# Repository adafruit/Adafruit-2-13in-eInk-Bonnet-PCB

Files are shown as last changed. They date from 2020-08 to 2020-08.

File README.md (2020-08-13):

## Adafruit 2.13" Monochrome eInk Bonnet for Raspberry Pi PCB

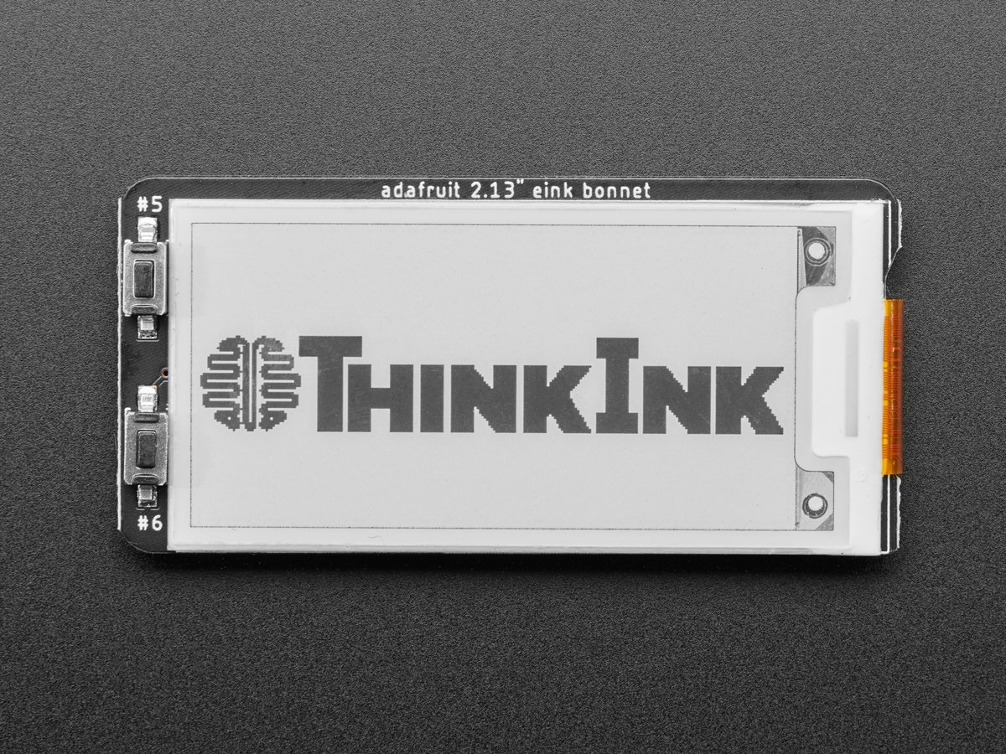
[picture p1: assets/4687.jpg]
<a href="http://www.adafruit.com/products/4687"><br/>
Click here to purchase one from the Adafruit shop</a>

PCB files for the Adafruit 2.13" Monochrome eInk Bonnet for Raspberry Pi.

Format is EagleCAD schematic and board layout
* https://www.adafruit.com/product/4687

### Description

Easy e-paper finally comes to Raspberry Pi, with this bonnet that's designed to make it a breeze to add a 2.13" 250x122 crisp monochromic eInk display. Chances are you've seen one of those new-fangled 'e-readers' like the Kindle or Nook. They have gigantic electronic paper 'static' displays - that means the image stays on the display even when power is completely disconnected. The image is also high contrast and very daylight readable. It really does look just like printed paper!

The Adafruit 2.13" Monochrome E-Ink Bonnet for Raspberry Pi snaps onto any modern Raspberry Pi and provides a Python-programmable display with two buttons that can be used to select programs or scroll through options.

We have two fun starter guides to use with this bonnet, an Open Weather display and an event calendar that auto-syncs with a Google Calendar to show you what your next meeting or event is. We also have examples in our E-Ink Python library you can use to craft your own project

Comes completely pre-assembled and tested so you don't need to do anything but plug it in and install our Python code! Works with any Raspberry Pi computer that has a 2x20 connector, such as the Pi B+, Pi 2, Pi 3, Pi 4, and Pi Zero (and any others that have a 2x20 connector!)

On the bottom, we have a Qwiic/STEMMA QT connector for I2C sensors and devices so you can plug and play any of our STEMMA QT devices.

### License

Adafruit invests time and resources providing this open source design, please support Adafruit and open-source hardware by purchasing products from [Adafruit](https://www.adafruit.com)!

Designed by Limor Fried/Ladyada for Adafruit Industries.

Creative Commons Attribution/Share-Alike, all text above must be included in any redistribution.
See license.txt for additional details.

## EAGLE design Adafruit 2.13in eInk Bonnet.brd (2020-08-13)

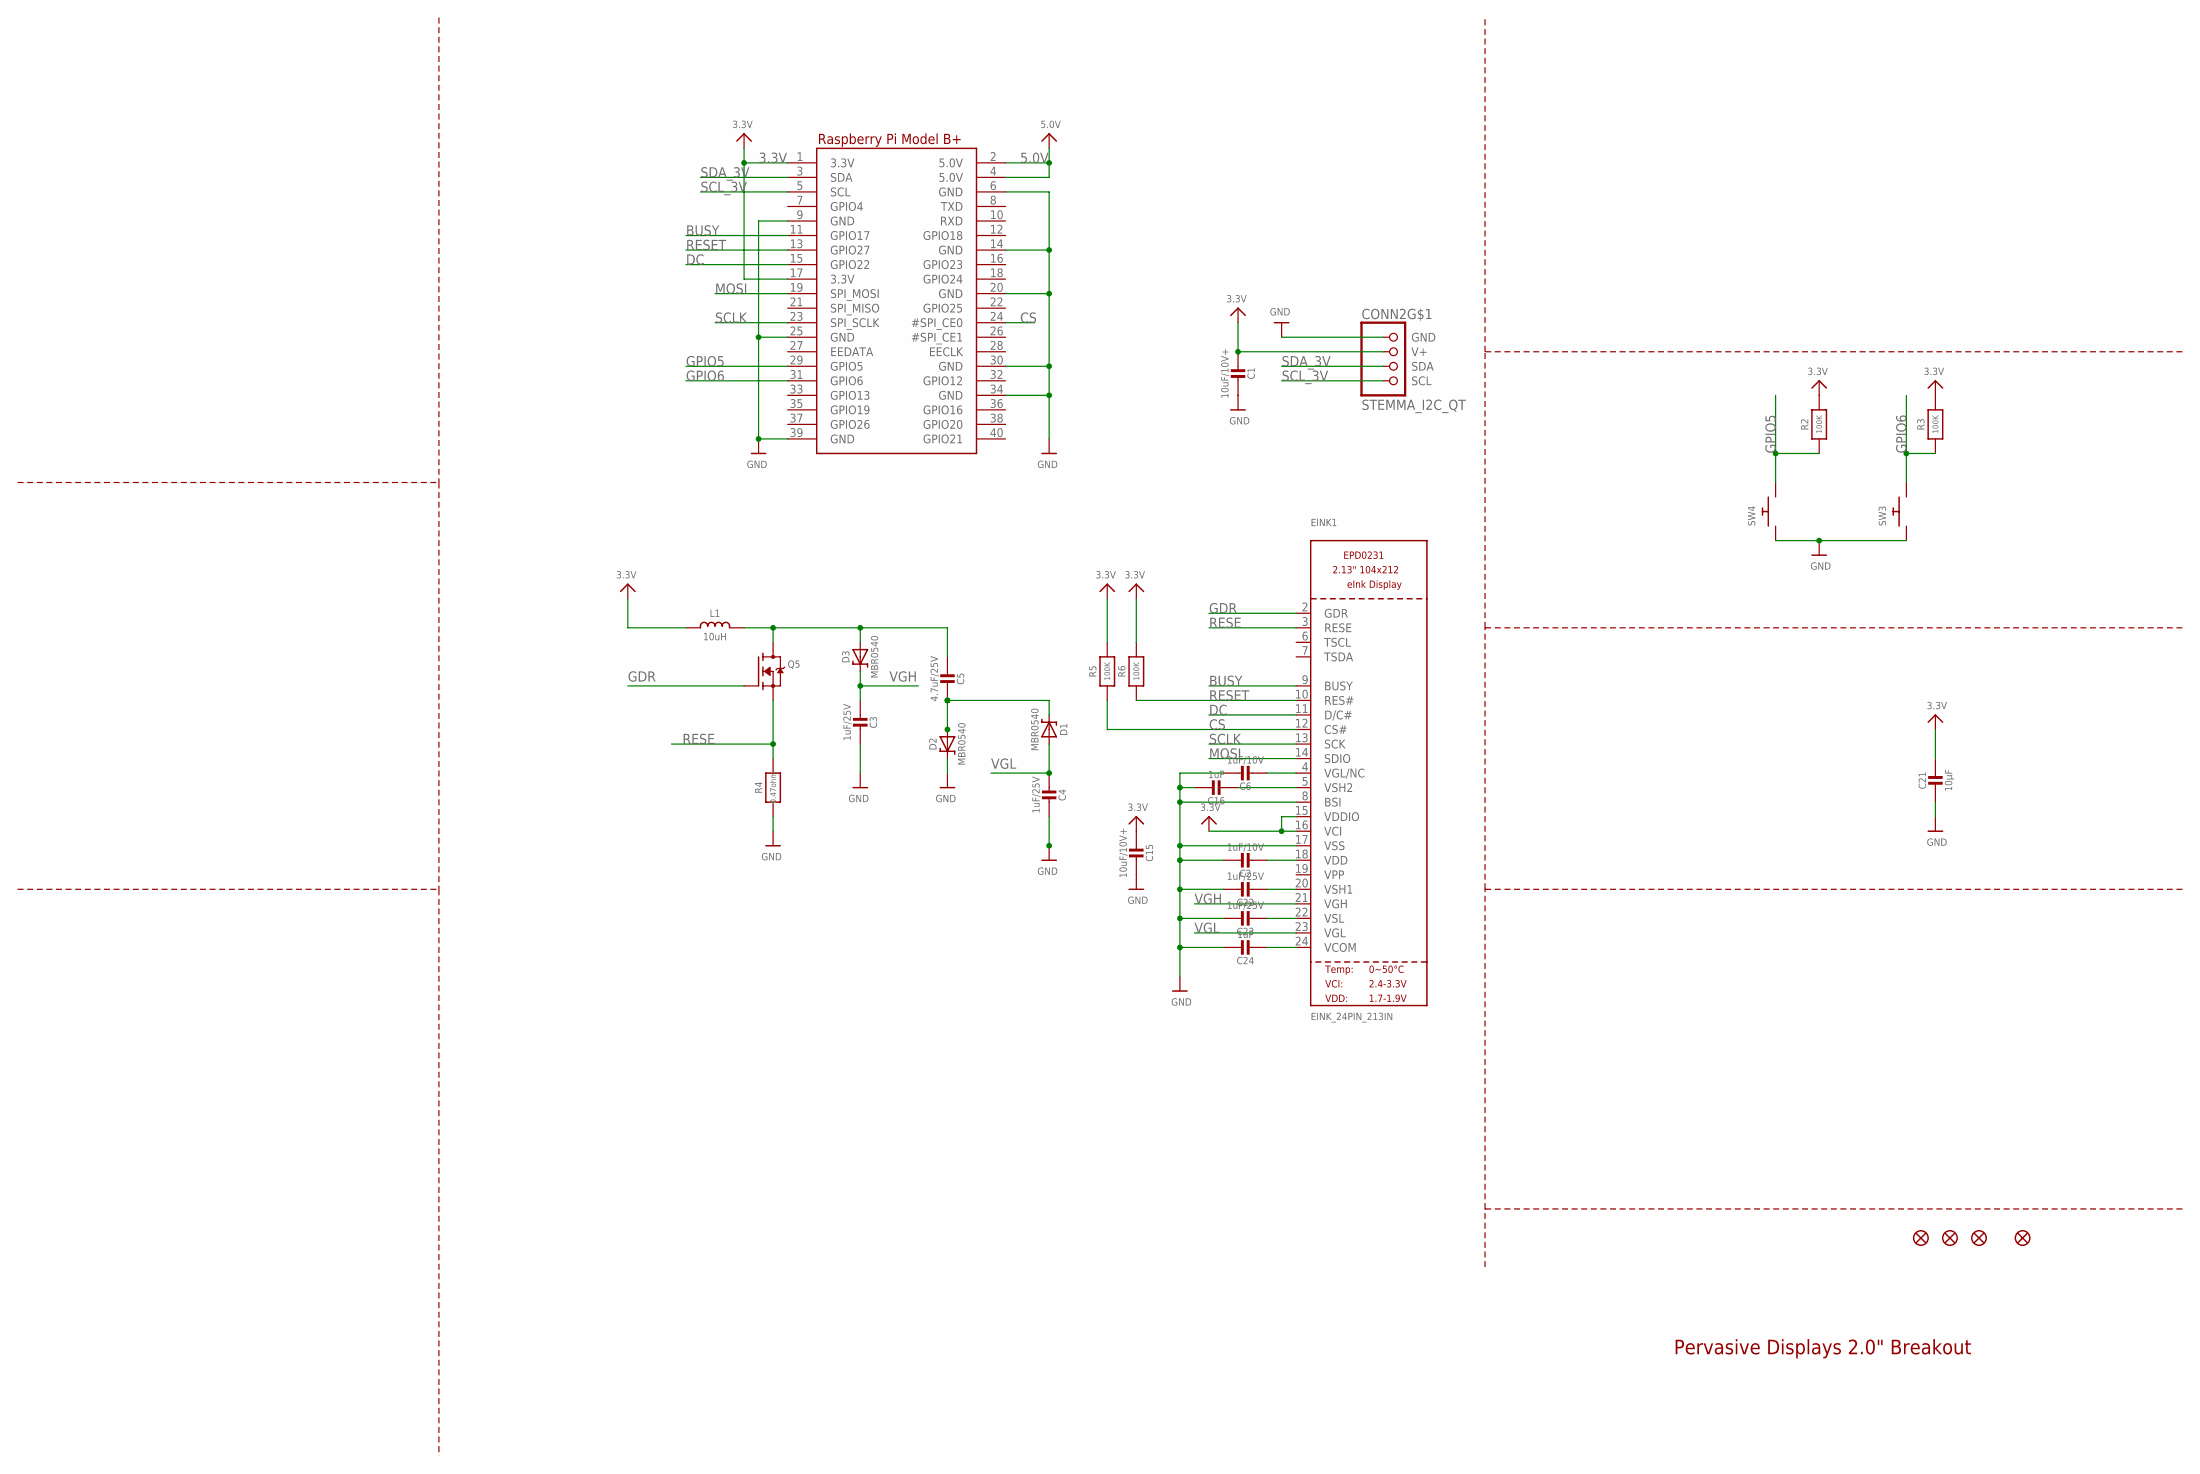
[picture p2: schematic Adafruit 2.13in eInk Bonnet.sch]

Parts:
C1, C15: 10uF/10V+; 0805-NO
C2, C6: 1uF/10V; 0805-NO
C3, C4, C22, C23: 1uF/25V; 0805-NO
C5: 4.7uF/25V; 0805-NO
C16, C24: 1uF; 0805-NO
C21: 10µF; 0805-NO
CONN2: STEMMA_I2C_QT; JST_SH4
D1, D2, D3: MBR0540; SOD-123
EINK1: EINK_24PIN_213IN; EINK_213IN_104X212
FID1, FID2, FID3, FID4: FIDUCIAL_1MM
L1: 10uH; INDUCTOR_4X4MM_NR401
Q5: IRLML0100; SOT23-3
R2, R3, R5, R6: 100K; 0603-NO
R4: 0.47ohm; 0805_10MGAP
RPI2: RASPBERRYPI_BPLUS_SMT_NODIM; PI_BONNET_SMT_NODIM
SW3, SW4: SWITCH_PUSHBUTTON_3.5X6MM; TACTILE_3X6MM

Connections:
3.3V: C1.2, C15.2, C21.1, CONN2.2 (V+), EINK1.15 (VDDIO), EINK1.16 (VCI), L1.P$2 (2), R2.2, R3.2, R5.2, R6.2, RPI2.1 (3.3V), RPI2.17 (3.3V)
5.0V: RPI2.2 (5.0V), RPI2.4 (5.0V)
BUSY: EINK1.9 (BUSY), RPI2.11 (GPIO17)
CS: EINK1.12 (CS#), R5.1, RPI2.24 (#SPI_CE0)
DC: EINK1.11 (D/C#), RPI2.15 (GPIO22)
GDR: EINK1.2 (GDR), Q5.1 (G)
GND: C1.1, C2.1, C3.2, C4.2, C6.1, C15.1, C16.1, C21.2, C22.1, C23.1, C24.1, CONN2.1 (GND), D2.C, EINK1.8 (BSI), EINK1.17 (VSS), R4.2, RPI2.6 (GND), RPI2.9 (GND), RPI2.14 (GND), RPI2.20 (GND), RPI2.25 (GND), RPI2.30 (GND), RPI2.34 (GND), RPI2.39 (GND), SW3.P$1, SW4.P$1
GPIO5: R2.1, RPI2.29 (GPIO5), SW4.P$2
GPIO6: R3.1, RPI2.31 (GPIO6), SW3.P$2
MOSI: EINK1.14 (SDIO), RPI2.19 (SPI_MOSI)
unnamed: C5.2, D1.C, D2.A
unnamed: C5.1, D3.A, L1.P$1 (1), Q5.3 (D)
unnamed: C16.2, EINK1.5 (VSH2)
unnamed: C2.2, EINK1.18 (VDD)
unnamed: C22.2, EINK1.20 (VSH1)
unnamed: C6.2, EINK1.4 (VGL/NC)
unnamed: C23.2, EINK1.22 (VSL)
unnamed: C24.2, EINK1.24 (VCOM)
RESE: EINK1.3 (RESE), Q5.2 (S), R4.1
RESET: EINK1.10 (RES#), R6.1, RPI2.13 (GPIO27)
SCLK: EINK1.13 (SCK), RPI2.23 (SPI_SCLK)
SCL_3V: CONN2.4 (SCL), RPI2.5 (SCL)
SDA_3V: CONN2.3 (SDA), RPI2.3 (SDA)
VGH: C3.1, D3.C, EINK1.21 (VGH)
VGL: C4.1, D1.A, EINK1.23 (VGL)

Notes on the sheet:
Pervasive Displays 2.0" Breakout

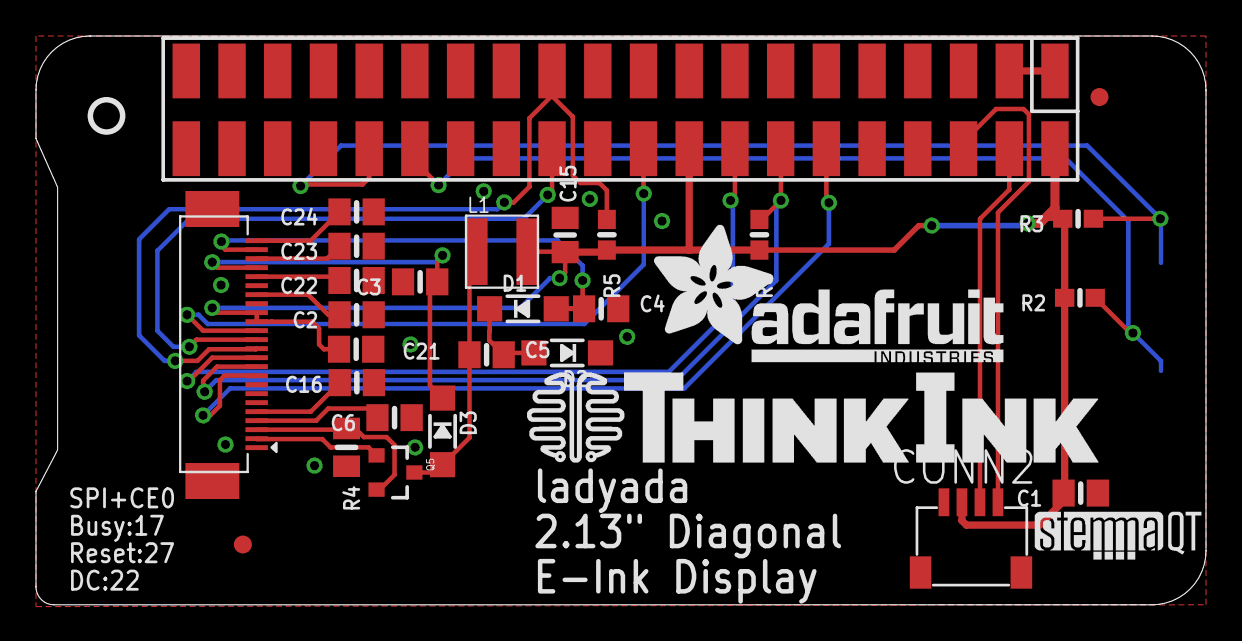
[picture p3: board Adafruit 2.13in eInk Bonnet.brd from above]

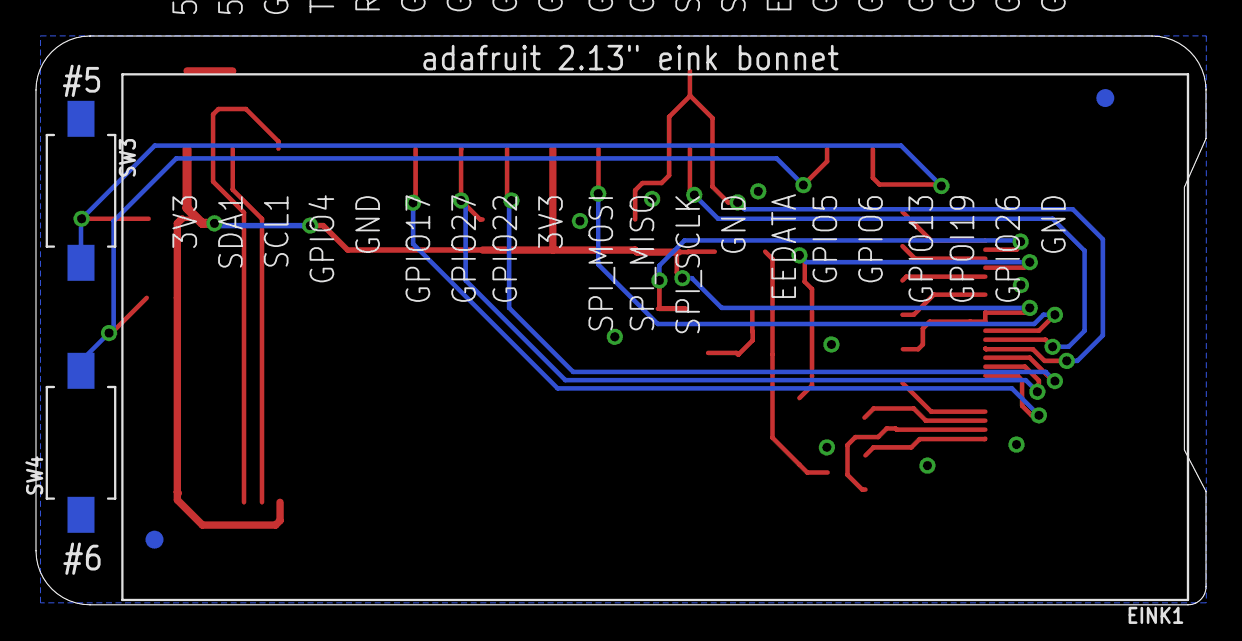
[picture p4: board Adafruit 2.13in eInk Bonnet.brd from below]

Board: 2 copper layers, 65.0 x 31.6 mm, 35 parts (6 on the bottom side), 25 nets.

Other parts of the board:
U$9: PCBFEAT-REV-040
U$28: ADAFRUIT_TEXT_20MM
U$29: THINKINK_1.25IN
U$30: STEMMAQT

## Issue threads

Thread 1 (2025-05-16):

Silkscreen GPIO Numbering

mikeysklar, 2025-05-16:
The left far left side of the 2.13" eInk bonnet has two buttons labeled #5 and #6.

They both work, but the silkscreen does not match the GPIO numbers.

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

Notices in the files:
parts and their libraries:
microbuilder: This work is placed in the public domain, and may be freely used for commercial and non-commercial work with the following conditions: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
